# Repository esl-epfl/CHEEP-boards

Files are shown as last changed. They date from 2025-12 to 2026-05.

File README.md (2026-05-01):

# Welcome to the CHEEP boards!

This is a set of PCBs to test, in principle, [X-HEEP](github.com/esl-epfl/x-heep) chips (CHEEPs)... but, you can use it to test any chip you want, for what it matters.

The general idea is to recycle efforts, so all the things that are common to any CHEEP were moved into a **main board**. This one includes an FTDI through which you can program or communicate with your cheep, as well as some peripherals like flash, buttons, LEDs, etc. The main board also generates all the voltages needed by these blocks.

On the sides of the main board you will find slots for **chewing gums**, these are chewing-gum-shaped custom-boards that can do pretty much whatever you want them to. We have designed some that provide a configurable voltage and the extras needed to measure current being drained.

Almost everything that is on the main board, including the outputs of the chewing gums, go to a large 150-positions connector at the bottom of the PCB. You can then design for each cheep a custom **breakout board** that takes the signals that you need from that connector.

Bellow you can find some extra information on each of these parts.

## Main board

The objective of the mainboard is to include everything your cheep needs so that your breakout board can be as simple as a footprint for your cheep/socket wired to the connector.

It is controlled through a USB-C connector directly from your PC. From that USB you can power up the whole board and control the FTDI.

You can alternativelly power up the board with an external DC power supply through the jack of banana connector.

The FTDI is the same used on the [EPFL programmer](github.com/esl-epfl/x-heep-programmer-pmod), so you can directly command it through the `make` commands on X-HEEP.

The UART of the FTDI is also made available in the same way that it was on X-HEEP, so you just open picocom or any serial viewer to read the UART output of your CHEEP from your PC.

We use level shifters all around so that your chip can operate at any IO voltage you want. You can select the IO voltage on the main board through some jumpers with pre-defined values, or with a trimmer.

Additionally, through the FTDI you can control any of the I2C devices on the board, on the chewing gums, or on the breakout board. Check the [Software stack](./software_stack/) for the python tools for this. Components that are mapped include:
* **GPIO expanders** - so you can control (read/write) GPIOs and interface with your cheep through them (software stack pending)
* **PLL** - You can supply your cheep with different clocks, from 4 kHz to 200 MHz. Just check the [PLL software stack](./software_stack/python/pll_controller.py).
* **Chewing gums** - You can configure things on the chewing gums (e.g. read from on-board ADCs or set DAC values).

### 🪲 Bugs and needed improvements
* We need contributions on the software stack to control the chewing gums and on-board GPIOs.
* Setting different on-board IO voltages introduces weird behaviors on the LEDs, some of which are floating to be controlled by the breakout board. We should handle this better.

## 150 positions connector

You cancheck the [standard](./docs/150%20pin%20cheep%20board%20connector%20standard.pdf):


</p>

There is also a symbol and footprint you can use in your PCB to make sure you are using the right assignment.

## Chewing gums

So far we have designed 2 chewing gums that can be found on [the chewing gum folder](./chewing-gums/):

### PosNeg supply
As the name suggests, allows to produce a positive or negative supply (from the main-board-generated -5V reference).

### Current Measurement Supply

It's an voltage reference with a shunt to measure current. You can:
* Set the LDO reference through an on-board trimmer.
* Set the LDO reference through an on-board DAC (needs software stack to command it through I2C)
* Put different SMD resistor values (needs soldering :/)
* The shunt's voltage drop is amplified by an on-board amplifier (INA). Its output is made available on the SMA connector on the back. You can configure its gain through some pads on the bottom. You better measure against a known current before using these (e.g. I have measured the gain to be 1729 V/V with a 12 µV input referred offset with the default configurations). This will strongly affect your measurements!
* We left a 1 MΩ resistor to ground that you can use to make this calibration measurement.

## Creating your own

You can create your own chewing gum and contribute it to this project. You can use [the template](./chewing-gums/template/) to make sure you use the right footprint and pinout :)

### 🪲 Bugs and needed improvements
* We missed a 180 kΩ resistor in series between the DAC output and the LDO reference (in case you want to control them through DAC)
* It would be nice to have a TH connector for the shunt in case you want to use different ranges
* It would be nice to have a TH connector for the LDO resistive divider in case you want to use different ranges

## Your custom breakout board

You can make your own custom breakout board to take things from the main board and chewing gums. Whatever you are missing, you can always just add it to the breakout board, it ain't illegal...

You can take [the HEEPidermis breakout board](https://github.com/esl-epfl/HEEPidermis-breakout-board/tree/main) as an example.

## I2C Address Tree
The CHEEP mainboard uses TI TCA9548A (https://www.ti.com/lit/ds/symlink/tca9548a.pdf) I2C Multiplexers in order to allow to isolate the chewing gum boards from each other and to minimise the risk of I2C address conflicts.
### 0b1110000 / 0x70 - Left I2C Expander
#### PORT 0 - Chewing gum board 3
#### PORT 1 - Chewing gum board 2
#### PORT 2 - Chewing gum board 1
#### PORT 3 - Chewing gum board 4
#### PORT 4 - Chewing gum board 5
#### PORT 5 - Chewing Gum Board 6
#### PORT 6 - CHEEP CHIP PCB Connector
#### PORT 7 - CHEEP Board Infrastructure
#####
### 0b1110000 / 0x70 - Right I2C Expander

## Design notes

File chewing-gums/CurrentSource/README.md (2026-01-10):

# Overview

This chewing gum board is designed to be a current source and intended for connection to the main board through the male pin headers to both sides. It can produce a current output from 600 nA to 1.4 uA, usually as an external bias current to the analog blocks in the test chip.
# User guide and programmability

It is a single-channel current source based on the LM334 IC. It is capable of outputting from 600 nA to 1.4 uA using the resistor network, with a potentiometer that allows to adjust the output within this range. (Note that this output current range can be extended up to 10 mA by changing the values of resistors R2, R3 and RV1, check schematic and datasheet).

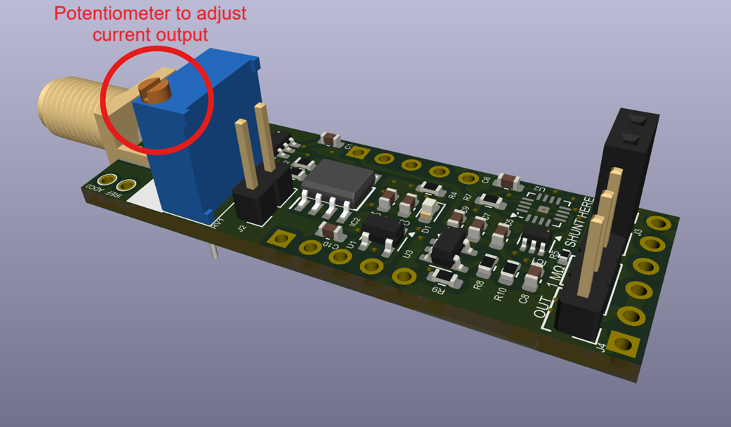
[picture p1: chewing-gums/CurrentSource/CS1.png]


The LM334 is powered by 3.3 V, however, unless the J2 jumper is connected, the current source IC will not be powered. Once it is powered-up by connecting the jumper, the LED should turn on.

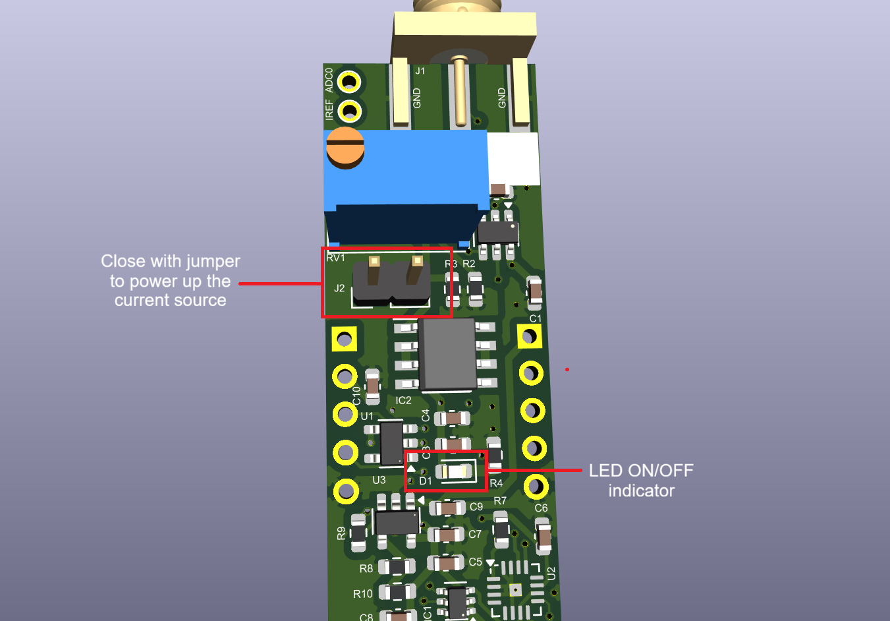
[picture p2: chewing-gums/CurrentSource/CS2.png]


Similar to other chewing gum boards (e.g., see _CurrentMeasurementSupply_), the current source board can be use to obtain a reading of the output current. All the current measurement circuits are kept unchanged and therefore can be used in the same way by employing shunt resistors + the ADC reading.

Female pin header J3 can be used to connect a through-hole resistor for current measurement. This allows for quicker replacement of the shunt resistor values, as opposed to the SMD alternatives.

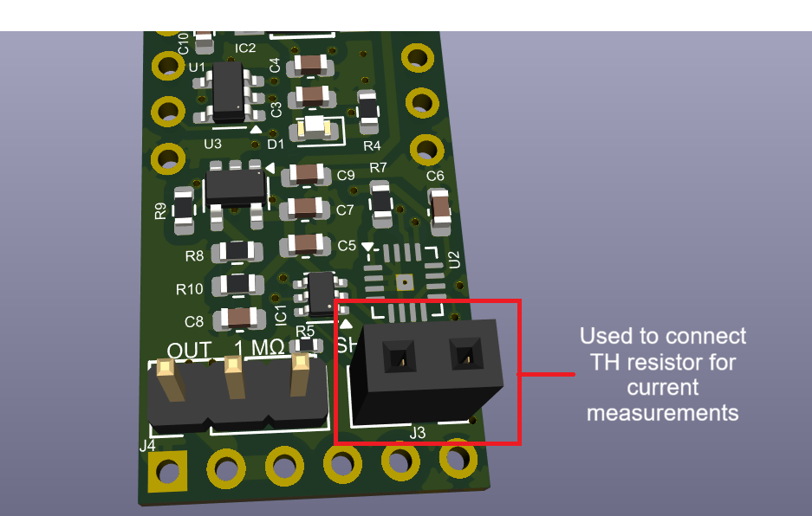
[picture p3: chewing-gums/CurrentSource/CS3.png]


The "IREF" test point next to the SMA connector can also be used to measure the voltage at the output of the current source. 

## Use of the DAC and EN pins

In this board, both the external EN pin to the board and the DAC are kept unused. This is because the current source IC is not compatible with either of these functions. However, the DAC is kept in the board for a possible future use.

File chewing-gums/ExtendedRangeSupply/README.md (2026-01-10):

# Overview

This chewing gum board is designed to be an extended-range voltage supply + current measurement circuit, intended for connection to the main board through the male pin headers to both sides. It can produce a voltage output from 0 to 5 V approximately, with currents of up to 1 A (@nominal voltage, check datasheet).
# User guide and programmability

This chewing gum board is an adaptation of the _CurrentMeasurementSupply_ chewing gum and as such can be used in a similar way, the main difference being the wider supply voltage range. This Extended Range version, however, supports only a single voltage output ("A").

It is based on the TPS7A9401 IC. The output voltage is defined via a resistor network, with a potentiometer soldered to the board that allows to manually modify the output within this range.

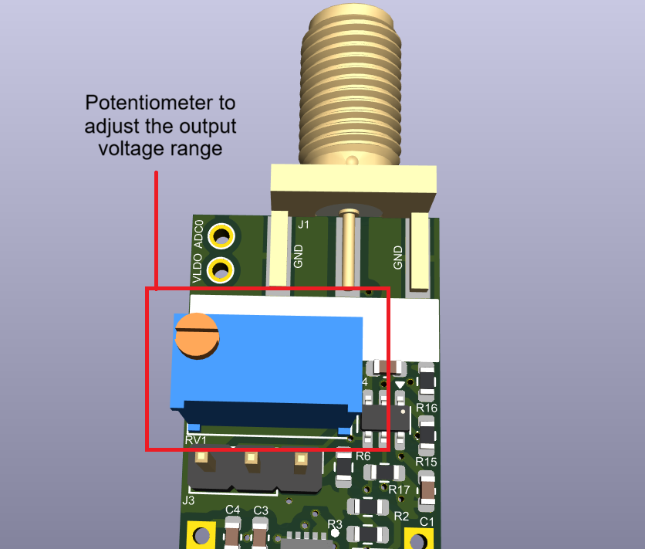
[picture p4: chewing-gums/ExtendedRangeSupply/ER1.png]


The TPS7A9401 is always ON and will operate when the EN pin is high. Either the external EN input, or the internal supply signal can be used to set the EN pin. This can be selected through the J2 jumper.

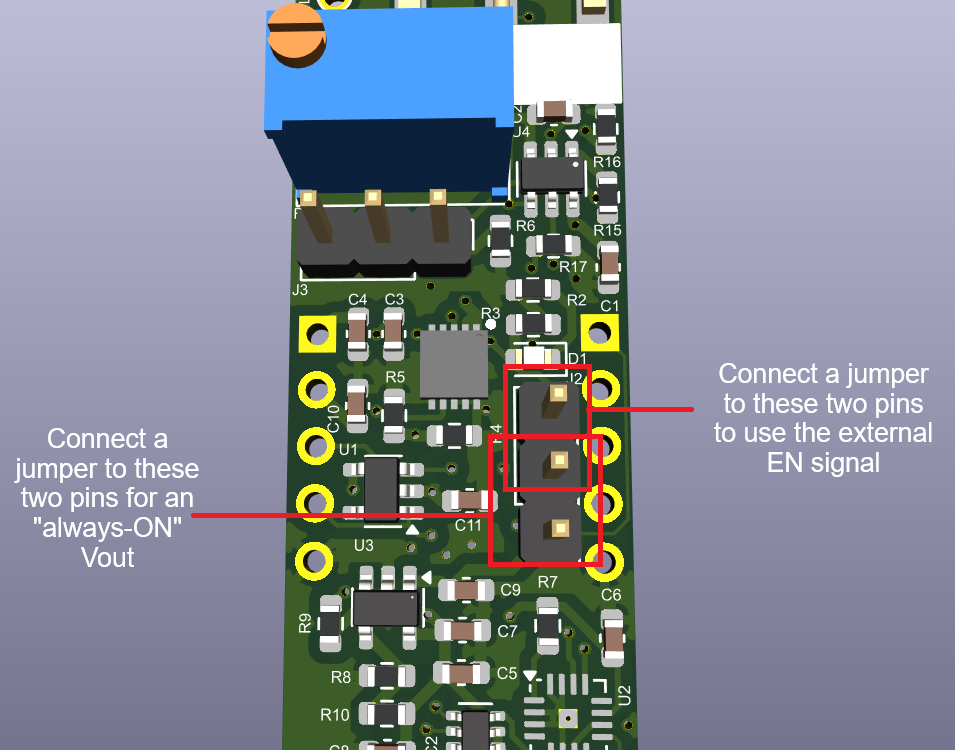
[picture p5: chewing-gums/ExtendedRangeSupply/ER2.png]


Similar to the _CurrentMeasurementSupply_ chewing gum board, this extended range version can also be use to obtain a reading of the output current. All the current measurement circuits are kept unchanged and therefore can be used in the same way by employing shunt resistors + the ADC reading. 

Female pin header J3 can be used to connect a through-hole resistor for current measurement. This allows for quicker replacement of the shunt resistor values, as opposed to the SMD alternatives.

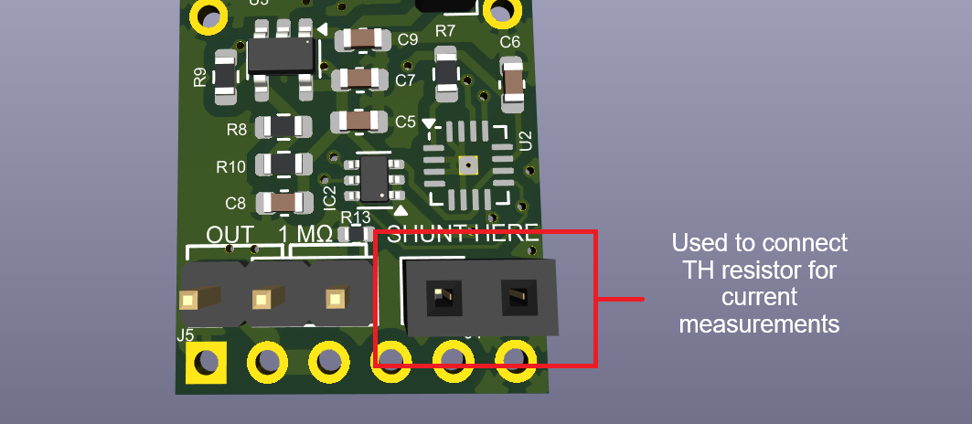
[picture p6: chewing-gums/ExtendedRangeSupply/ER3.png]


The "VLDO" test point next to the SMA connector can also be used to measure the output voltage.

## DAC programming

Besides using the potentiometer for trimming, the output voltage can also be adjusted by changing the input to the DAC. For this operation, however, resistors R15 and R16 need to be selected for this by carefully checking the possible voltage range with the datasheet.

Jumper J3 can be used to set potentiometer or DAC trimming.

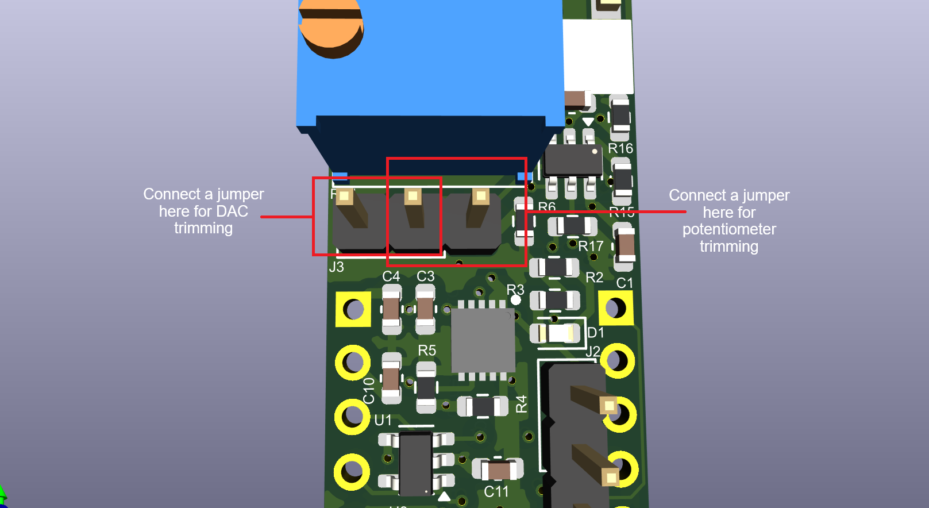
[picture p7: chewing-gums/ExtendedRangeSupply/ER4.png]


## Simulations

A macromodel of the TPS7A9401, together with a simplified circuit modeling its behavior in this board has been included. The simulation can be run using TINA-TI. This allows, for example, to change resistors and verify the output voltage of the TPS7A9401, as well as the output current when simulating with a load.

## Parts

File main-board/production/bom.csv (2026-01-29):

Designator | Footprint | Quantity | Value | LCSC Part #
C1, C10, C11, C12, C13, C14, C15, C16, C18, C2, C21, C24, C26, C27, C28, C29, C31, C32, C33, C34, C35, C36, C37, C38, C45, C46, C47, C49, C5, C50, C51, C52, C53, C54, C59, C65, C66, C7 | 0603 | 38 | 100nF | C30926
C17, C19, C60 | 0603 | 3 | 1uF | C15849
C20, C43 | 0603 | 2 | 10uF | C19702
C22, C30, C44 | 0603 | 3 | 22uF | C59461
C3, C4 | 0603 | 2 | 30pF | C1658
C39 | 0603 | 1 | 2.2uF | C1607
C40 | 0603 | 1 | 5.6nF | C1628
C41, C42, C8, C9 | 0603 | 4 | 4.7uF | C19666
C6 | 0603 | 1 | 3.3uF | C51412
C61 | CP_Elec_5x4.5 | 1 | 100uF | C7469933
D1, D10, D11, D12, D15, D16, D17, D18, D2, D3, D4, D5, D6, D7, D8, D9 | 0603 | 16 | LED | C84263
D13, D14 | D_SOD-882 | 2 | PESD3V3U1UL | C552530
D19, D20, D21, D22, D23, D24, D25 | 0603 | 7 | LED | C965804
D26 | 0603 | 1 | LED | C84266
IC10, IC2, IC3 | TI-UQFN-16 | 3 | SN74AXC4T774RSVR | C1849454
IC13 | TI-VQFN-HR-12 | 1 | TPS2121RUXR | C485916
J2, J66 | Banana_Jack_1Pin | 2 | Conn_01x01_Socket
J3 | PinSocket_1x04_P2.54mm_Vertical | 1 | Conn_01x04 | C124413
J47 | BarrelJack_GCT_DCJ200-10-A_Horizontal | 1 | Barrel Jack | C136744
J6 | PinHeader_1x03_P2.54mm_Vertical_SMD_Pin1Right | 1 | Conn_01x03 | C5160786
J7 | SMA_Amphenol_901-144_Vertical | 1 | Conn_Boaxial | C2987686
J73 | PinSocket_1x03_P2.54mm_Vertical | 1 | Conn_01x03 | C5116529
J8 | USB_C_Receptacle_GCT_USB4105-xx-A_16P_TopMnt_Horizontal | 1 | USB_C_Receptacle_USB2.0_16P | C5184243
J9 | PinHeader_2x04_P2.54mm_Vertical_SMD | 1 | Conn_02x04_Odd_Even | C192300
L1, L2 | 0603 | 2 | 600nH | C280244
L3 | L_Vishay_IHLP-2020 | 1 | 10uH | C844996
R1, R100, R101, R102, R103, R104, R105, R106, R107, R108, R109, R110, R12, R13, R24, R25, R26, R3, R31, R32, R33, R34, R35, R36, R37, R38, R39, R40, R41, R42, R45, R53, R65, R72, R80, R81, R82, R83, R84, R85, R86, R87, R88, R89, R90, R91, R92, R93, R94, R96, R97, R98, R99 | 0603 | 53 | 10k | C98220
R10, R11, R116, R117, R14, R16, R30, R74, R75 | 0603 | 9 | 1k | C21190
R111, R112, R113, R114, R115, R15, R17, R18, R19, R20, R21, R22, R23, R27, R63, R66, R77, R79, R95 | 0603 | 19 | 5k | C21190
R2 | 0603 | 1 | 12k 1% | C22790
R28, R29, R78 | 0603 | 3 | 5k | C22975
R4, R5, R70, R71 | 0603 | 4 | 25 | C1203
R43, R44, R58, R60 | 0603 | 4 | 5.1k | C23186
R46, R61 | 0603 | 2 | 100k | C25803
R47, R62, R69 | 0603 | 3 | 20k | C4184
R48 | 0603 | 1 | 51k | C23196
R49 | 0603 | 1 | 226k | C33619
R50 | 0603 | 1 | 49.9k | C23184
R51 | 0603 | 1 | 3.32M | C327396
R52 | 0603 | 1 | 1.33M | C482628
R54, R55 | 0603 | 2 | 5k | C22843
R56 | 0603 | 1 | 59k | C23085
R57, R59 | 0603 | 2 | 23.7k | C22912
R6, R7, R8, R9 | 0603 | 4 | 23.7k | C269480
R64 | 0603 | 1 | 4.7k | C99782
R67 | 0603 | 1 | 44.2k | C844365
R68 | 0603 | 1 | 86.6k | C23121
RV1 | Potentiometer_Bourns_3296W_Vertical | 1 | 500k | C83694
SW1, SW4, SW5, SW6, SW7 | SW_Push_1P1T_NO_CK_KMR2 | 5 | SW_Push | C221678
SW2 | SW_TE_1825255-1 | 1 | SW_DPST_x2
TP10, TP11, TP12, TP13, TP14, TP7, TP8, TP9 | TestPoint_Keystone_5019_Miniature | 8 | 5029 | C238131
U1 | LQFP-64_10x10mm_P0.5mm | 1 | FT4232HL | C56742
U10 | MSOP-10-1EP_3x3mm_P0.5mm_EP1.68x1.88mm | 1 | SI5351A-B-GTR | C504891
U11, U17 | TSSOP-20_4.4x6.5mm_P0.65mm | 2 | 74AHC244 | C7475
U12 | SOT-23-5 | 1 | 24AA02E-OT | C38987
U14, U28, U8 | VSSOP-10_3x3mm_P0.5mm | 3 | TS5A23159DGS | C42751
U15, U16 | BIWIN_DTS04GE_SMD | 2 | BIWIN_DTS04GE_SMD | C3294670
U18, U19 | SOT-23-5 | 2 | 74AHCT1G08 | C113521
U2 | SOIC-8_5.3x5.3mm_P1.27mm | 1 | W25Q128JVSIQ | C97521
U20 | SOT-23-5 | 1 | 74AHC1G04 | C7465
U21, U22 | Texas_RGE0024C_VQFN-24-1EP_4x4mm_P0.5mm_EP2.1x2.1mm | 2 | TCA9548ARGER | C555456
U23 | CHEEP_CONNECTOR_MAINBOARD | 1 | ~
U24 | Texas_R-PUQFN-N12 | 1 | TXBN0304RUT | C201558
U25, U26 | Texas_R-PUQFN-N12 | 2 | TXB0304RUT | C69598
U3, U5 | SOT-23-5 | 2 | TLV75801PDBV | C2877852
U4 | MAX17577-12-TDFN-EP | 1 | MAX17577 | C2930958
U6, U7 | WQFN-24-1EP_4x4mm_P0.5mm_EP2.6x2.6mm | 2 | TCAL6416 | C5956642
U9 | SOT-353_SC-70-5 | 1 | 74AHCT1G08 | C460499
X1 | Oscillator_SMD_SeikoEpson_SG8002CE-4Pin_3.2x2.5mm | 1 | OK322532.768KJBA4SL | C725996
Y1 | Crystal_SMD_3225-4Pin_3.2x2.5mm | 1 | Crystal_GND24 | C9002
Y2 | Crystal_SMD_3225-4Pin_3.2x2.5mm | 1 | NX3225GA-25.000M-STD-CRG-2 | C1985619

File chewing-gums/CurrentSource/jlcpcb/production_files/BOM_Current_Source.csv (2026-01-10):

Comment | Designator | Footprint | LCSC | Qty
0.1u | C1,C2,C4,C5,C6,C7,C8,C10 | Capacitor_SMD:C_0603_1608Metric | C1590 | 7
10k | R7,R9 | Resistor_SMD:R_0603_1608Metric | C98220 | 2
10u | C3 | Capacitor_SMD:C_0603_1608Metric | C19702 | 1
1u | C9 | Capacitor_SMD:C_0603_1608Metric | C1592 | 1
LED | D1 | LED_SMD:LED_0603_1608Metric | C2286 | 1
INA212AIDCKR | IC1 | Package_TO_SOT_SMD:SOT-363_SC-70-6 | C128622 | 1
LM334M_NOPB | IC2 | LM334:SOIC127P600X175-8N | C1524129 | 1
Conn_Coaxial | J1 | Connector_Coaxial:SMA_Amphenol_132289_EdgeMount | C1509219 | 1
75k | R2 | Resistor_SMD:R_0603_1608Metric | C2074221 | 1
140k | R3 | Resistor_SMD:R_0603_1608Metric | C860114 | 1
3.3k | R4 | Resistor_SMD:R_0603_1608Metric | C2907023 | 1
1M | R5 | Resistor_SMD:R_0402_1005Metric | C326730 | 1
20k | R8 | Resistor_SMD:R_0603_1608Metric | C4184 | 1
100k | R10 | Resistor_SMD:R_0603_1608Metric | C25803 | 1
500k Potentiometer | RV1 | Potentiometer_THT:Potentiometer_Bourns_3296W_Vertical | C83694 | 1
24AA02E-OT | U1 | Package_TO_SOT_SMD:SOT-23-5 | C38987 | 1
ADS1219 | U2 | Package_DFN_QFN:Texas_RTE0016D_WQFN-16-1EP_3x3mm_P0.5mm_EP0.8x0.8mm_ThermalVias | C2670319 | 1
TLV75801PDBV | U3 | Package_TO_SOT_SMD:SOT-23-5 | C2877852 | 1
MCP4726 | U4 | Package_TO_SOT_SMD:TSOT-23-6 | C191581 | 1

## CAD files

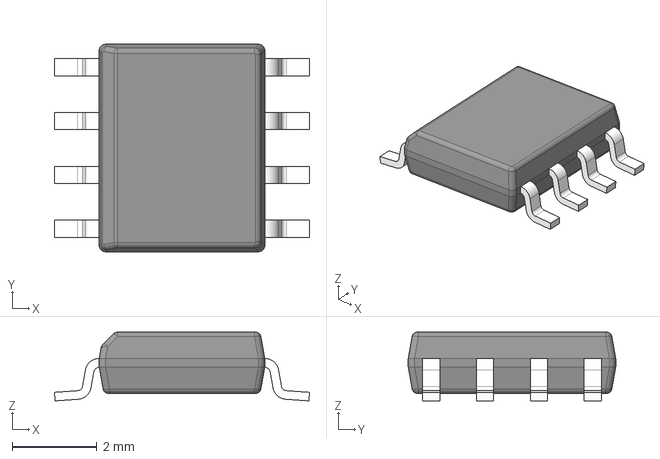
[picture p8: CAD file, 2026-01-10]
chewing-gums/CurrentSource/LM334/LM334M_NOPB.stp
6.02 x 4.90 x 1.63 mm
BODY-SO
LEAD-D0008A x 8

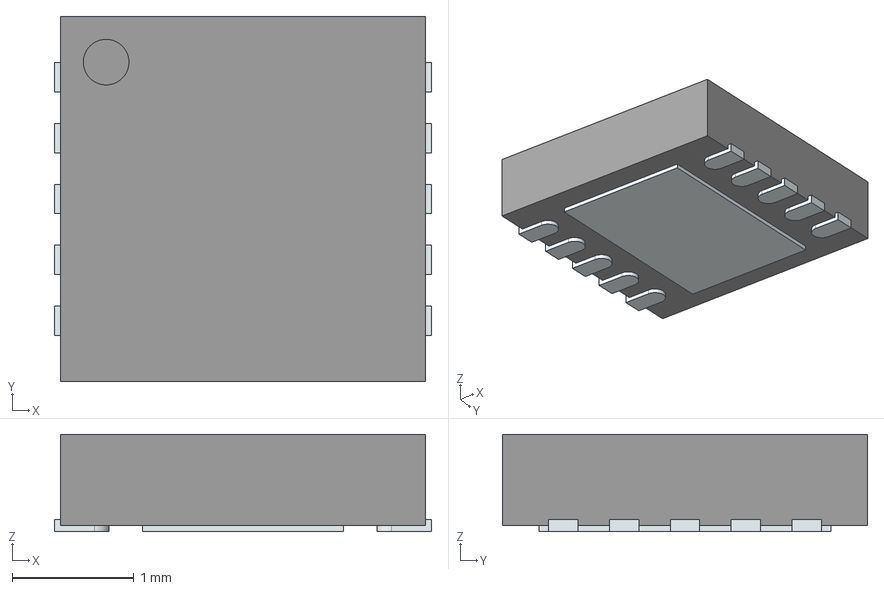
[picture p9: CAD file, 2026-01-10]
chewing-gums/ExtendedRangeSupply/TPS7A9401DSCR/TPS7A9401DSCR.stp
3.10 x 3.00 x 0.8 mm
ThermalPin
PinsArrayLR

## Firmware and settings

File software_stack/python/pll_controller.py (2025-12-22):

#from machine import Pin, I2C
from pll_i2c_wrapper import *
from pll_registers import PLLReg
#from utime import sleep_ms
from time import sleep



class PLLController:
    """
    Control PLL frequencies using an I2CWrapper.

    Attribuites:
        crystalFreq (int): Frequency of the srystal oscillator.

    Parameters:
        I2Cwrapper: Wrapper for I2C communication.
        crystalFreq (int): Frequnecy of the crystal oscillator. Defaults to PLLReg.CRYSTAL_FREQ_25MHZ.
    Reference:
        https://github.com/roseengineering/MicroPython-si5351.py
    """

    def __init__(self, I2CWrapper, crystalFreq = PLLReg.CRYSTAL_FREQ_25MHZ) -> None:
        """
        Initialize the PLLController.

        Parameters:
            I2CWrapper: Wrapper for I2C communication.
            crystalFreq (int): Frequency of the crystal oscialltor. Defaults to PLLReg.CRYSTAL_FREQ_25MHZ.


        """
        self.crystalFreq = crystalFreq
        self.plla_freq = 0
        self.communication = I2CWrapper

        clk_control_mapping = {
            0:  PLLReg.CLK0_CONTROL,
            1:  PLLReg.CLK1_CONTROL,
            2:  PLLReg.CLK2_CONTROL,
            3:  PLLReg.CLK3_CONTROL,
            4:  PLLReg.CLK4_CONTROL,
            5:  PLLReg.CLK5_CONTROL,
            6:  PLLReg.CLK6_CONTROL,
            7:  PLLReg.CLK7_CONTROL
        }
        self.clk_control_dict = clk_control_mapping

        multisynth_parameter1_mapping = {
            0: PLLReg.MULTISYNTH0_PARAMETERS_1,
            1: PLLReg.MULTISYNTH1_PARAMETERS_1,
            2: PLLReg.MULTISYNTH2_PARAMETERS_1,
            3: PLLReg.MULTISYNTH3_PARAMETERS_1,
            4: PLLReg.MULTISYNTH4_PARAMETERS_1,
            5: PLLReg.MULTISYNTH5_PARAMETERS_1,
            6: PLLReg.MULTISYNTH6_PARAMETERS_1
        }
        self.multisyn_p1 = multisynth_parameter1_mapping

        multisynth_parameter3_mapping = {
            0: PLLReg.MULTISYNTH0_PARAMETERS_3,
            1: PLLReg.MULTISYNTH1_PARAMETERS_3,
            2: PLLReg.MULTISYNTH2_PARAMETERS_3,
            3: PLLReg.MULTISYNTH3_PARAMETERS_3,
            4: PLLReg.MULTISYNTH4_PARAMETERS_3,
            5: PLLReg.MULTISYNTH5_PARAMETERS_3,
            6: PLLReg.MULTISYNTH6_PARAMETERS_3
        }
        self.multisyn_p3 = multisynth_parameter3_mapping


        #reset all clk outputs
        self.reg_write(PLLReg.OUTPUT_ENABLE_CONTROL, 0xFF)
        for clk_ctrl in range(0,8):
            self.reg_write(self.clk_control_dict.get(clk_ctrl), 0x80)

    def reg_write(self, address, data) -> None:
        """
        Write data to register.

        Parameter:
            address (int): Register address.
            data (int): Data to be written to the register.
        """

        self.communication.write_data(address, data)

    def reg_read(self, address: int) -> int:
        """
        Read data from a register.

        Parameters:
            address (int): Register address.

        Returns:
            int: Data read from the register.
        """
        data = self.communication.read_data(address, num_bytes=1)
        return data


    def set_frequency(self, target_frequency: int, output: int = 0, pll: int = PLLReg.PLL_A, mult: int = 32, roundit: bool = False) -> None:
        """
        Set the frequency of the PLL to the target_frequency.
        Decides if a frequency is below the minimum frequency. R divider needed for frequency lower then 500kHz down to 4kHz.
        Checks if the desired frequency is less then 500kHz down to 4kHz. If so then use resistors.
        Initilaize the Feedback Multiplier.

        Parameters:
            target_frequency (int): Desired frequency for the PLL.
            output (int): Choose the output clock (clk0-clk7).
            pll (int): Choose which PLL (A or B) provides f_vco.
            roundit (bool): Rounds fraction division to nearest int value. Reduces jitter by loss of frequency precision.
        """
        print(f"------------------------------------\n Set frequency to \n {target_frequency} \n")

        if (target_frequency >= 120_000_000):
            self.high_speed(target_frequency, output, pll, roundit)
            return

        mult = 36 # input clk multiplier must be between 15 and 90

        self.setup_feedbackMultisynth(pll, mult, 0, 1)

        freq = target_frequency
        r_div = PLLReg.R_DIV_1
        register = 60 #MULTISYNTH2_PARAMETERS_1
        print("R not hitted")
        if (freq >= PLLReg.CLKOUT_MIN_FREQ and freq < PLLReg.CLKOUT_MIN_FREQ * 2):
            r_div = PLLReg.R_DIV_128
            freq *= 128
            print(f"R hitted: {r_div}")
        elif (freq >= PLLReg.CLKOUT_MIN_FREQ*2 and freq < PLLReg.CLKOUT_MIN_FREQ * 4):
            r_div = PLLReg.R_DIV_64
            freq *= 64
            print(f"R hitted: {r_div}")
        elif (freq >= PLLReg.CLKOUT_MIN_FREQ*4 and freq < PLLReg.CLKOUT_MIN_FREQ * 8):
            r_div = PLLReg.R_DIV_32
            freq *= 32
            print(f"R hitted: {r_div}")
        elif (freq >= PLLReg.CLKOUT_MIN_FREQ*8 and freq < PLLReg.CLKOUT_MIN_FREQ * 16):
            r_div = PLLReg.R_DIV_16
            freq *= 16
            register = 44 # MULTISYNTH0_PARAMETERS_1
            print(f"R hitted: {r_div}")
        elif (freq >= PLLReg.CLKOUT_MIN_FREQ*16 and freq < PLLReg.CLKOUT_MIN_FREQ * 128):
            r_div = PLLReg.R_DIV_8
            freq *= 8
            register = 44 # MULTISYNTH0_PARAMETERS_1
            print(f"R hitted: {r_div}")
        elif (freq >= PLLReg.CLKOUT_MIN_FREQ*32 and freq < PLLReg.CLKOUT_MIN_FREQ * 64):
            r_div = PLLReg.R_DIV_4
            freq *= 4
            print(f"R hitted: {r_div}")
        elif (freq >= PLLReg.CLKOUT_MIN_FREQ*64 and freq < PLLReg.CLKOUT_MIN_FREQ * 128):
            r_div = PLLReg.R_DIV_2
            freq *= 2
            print(f"R hitted: {r_div}")

        if pll == PLLReg.PLL_A:
            fvco = self.plla_freq
        else:
            fvco = self.pllb_freq

        print(f"fvco: {fvco}")
        print(f"freq: {freq}")

        if roundit == True:
            num = fvco % freq
            denom = freq
            value = num/denom
            num = 0
            denom = 1
            div = fvco//freq
            if value >= 0.5:
                div += 1
        else:
            div = fvco // freq
            num = fvco % freq
            denom = freq

            if num == 0:
                denom = 1
            else:
                while denom > PLLReg.MULTISYNTH_C_MAX:
                    num //= 2
                    denom //= 2



        self.reset_pll()

        oe_ctrl = self.reg_read(PLLReg.OUTPUT_ENABLE_CONTROL)
        oe_cfg = oe_ctrl&(~(1<<output))
        print("oeb: {0:b}".format(oe_cfg))
        self.reg_write(PLLReg.OUTPUT_ENABLE_CONTROL, oe_cfg) #enable output clock

        self.setupMultisynth(output, div, num, denom)

        self.setupRdiv(output, r_div, register)



    def high_impedance(self, enable: bool) -> None:
        """
        Set the output of the PLL as high impedance if enable = True

        Parameters:
            enable (bool): Enable or disable high impedance.

        """
        self.reg_write(address=PLLReg.OUTPUT_ENABLE_CONTROL, data = 4 * enable) #maybe find a way to not have this 4 magic number


    def setup_feedbackMultisynth(self, pll: int, mult: int, num: int = 0, denom: int = 1) -> None:
        """
        Setup the feedback Multipath.

        Parameter:
            pll (int): Choose which PLL (A or B) provides f_vco.
            mult (int): PLL integer multiplier (must be between 15 and 90).
            num (int, optional): The 20-bit numerator for fractional output (0..1,048,575). Defaults to 0.
            denom (int, optional): The 20-bit numerator for fractional output (0..1,048,575). Defaults to 1.
        """
        print(f"\n Set feedback Multisynth \n")

        # Set the main PLL config registers
        print(f"mult: {mult}, num: {num}, denom: {denom}")

        P1 = 128 * mult + int(128.0 * num / denom) - 512
        P2 = 128 * num - denom * int(128.0 * num / denom)
        P3 = denom

        print(f"P1: {P1}")
        print(f"P2:  {P2}")
        print(f"P3:  {P3}")

        baseaddr = 26 if pll == PLLReg.PLL_A else 34 #Register 34 for use of PLLB

        self.reg_write(baseaddr,     (P3 & 0x0000FF00) >> 8)
        #isolate bits[15:8] and send it to the register
        self.reg_write(baseaddr + 1, (P3 & 0x000000FF))
        self.reg_write(baseaddr + 2, (P1 & 0x00030000) >> 16)
        self.reg_write(baseaddr + 3, (P1 & 0x0000FF00) >> 8)
        self.reg_write(baseaddr + 4, (P1 & 0x000000FF))
        self.reg_write(baseaddr + 5, ((P3 & 0x000F0000) >> 12) | ((P2 & 0x000F0000) >> 16) )
        #P3 should also be shifted by 12 ??
        self.reg_write(baseaddr + 6, (P2 & 0x0000FF00) >> 8)
        self.reg_write(baseaddr + 7, (P2 & 0x000000FF))

        fvco = int(self.crystalFreq*mult + float(num) /denom)
        if pll == PLLReg.PLL_A:
            self.plla_freq = fvco
        else:
            self.pllb_freq = fvco


    def setupMultisynth(self, output: int, div: int, num: int, denom: int) -> None:
        """
        Setup Multisynth divider, which  determines the output clock frequency based on the specified PLL input.

        Parameter:
            output (int): Output channel to choose.
            pll (int): PLL input source (now only PLLA since we don't use spread or VCXO).
            div (int): Integer divider for Multisynth output.
            num (int): The 20-bit numerator for fractional output (0..1,048,575). Set this to '0' for integer output.
            denom (int): The 20-bit numerator for fractional output (0..1,048,575). Set this to '0' for integer output.
        """
        print(f"\n Set setup Multisynth \n")

        print(f"divisor {div}")

        # Set the main PLL config registers
        P1 = 128 * div + int(128.0 * num / denom) - 512
        P2 = 128 * num - denom * int(128.0 * num / denom)
        P3 = denom

        print(f"P1: {P1}")
        print(f"P2:  {P2}")
        print(f"P3:  {P3}")
        print(f"divisor: {div}, num: {num}, denom: {denom}")

        baseaddr = self.multisyn_p3.get(output)

        print(f"baseaddr: {baseaddr}")

        self.reg_write(baseaddr,     (P3 & 0x0000FF00) >> 8)

        #isolate bits[15:8] and send it to the register
        self.reg_write(baseaddr + 1, (P3 & 0x000000FF))
        self.reg_write(baseaddr + 2, (P1 & 0x00030000) >> 16)
        self.reg_write(baseaddr + 3, (P1 & 0x0000FF00) >> 8)
        self.reg_write(baseaddr + 4, (P1 & 0x000000FF))
        self.reg_write(baseaddr + 5, ((P3 & 0x000F0000) >> 12) | ((P2 & 0x000F0000) >> 16) )

        #P3 should also be shifted by 12 ??
        self.reg_write(baseaddr + 6, (P2 & 0x0000FF00) >> 8)
        self.reg_write(baseaddr + 7, (P2 & 0x000000FF))

        #configure the clk control and enable output
        #8mA drive strength, MS0 as CLK0 source, Clock not inverted, power up

        clkControlReg = 0x0F
        if num == 0 : clkControlReg |= (1 << 6) #sets register in integer mode

        self.reg_write(self.clk_control_dict.get(output), clkControlReg) # here if condition for multiple clock output

    def high_speed(self, target_frequency: int, output: int, pll: int, roundit: bool) -> None:
        """
        Sets frequencies from 120Mhz to 200Mhz (overclock possible up to 300MHz)

         Parameters:
            target_frequency (int): Desired frequency for the PLL.
            output (int): Choose the output clock (clk0-clk7).
            pll (int): Choose which PLL (A or B) provides f_vco.
            roundit (bool): Rounds fraction division to nearest int value. Reduces jitter by loss of frequency precision.
        """

        self.setupMultisynth(output, 4, 0, 1) # set the output_Multisynth to the needed divisor 4

        self.setupRdiv(output, PLLReg.R_DIV_1)

        #set the Multisynth2 Parameter to Divide by 4 Enable
        divby4 = self.reg_read(self.multisyn_p1.get(output))
        print(f"data type from read is: {divby4}")
        divby4 |= 0xC #set the register value to Divide by 4
        self.reg_write(self.multisyn_p1.get(output), divby4)

        clkControlReg = self.reg_read(self.clk_control_dict.get(output))
        clkControlReg |= (1<<6) #set the control_setup to integer mode
        self.reg_write(self.clk_control_dict.get(output), clkControlReg)

        div = (target_frequency*4) // PLLReg.CRYSTAL_FREQ_25MHZ
        num = ((target_frequency*4) % PLLReg.CRYSTAL_FREQ_25MHZ)//1_000_000
        denom = PLLReg.CRYSTAL_FREQ_25MHZ//1_000_000

        if roundit == True:
            value = num/denom
            num = 0
            denom = 1
            if value >= 0.5:
                div += 1

        self.reg_write(PLLReg.CRYSTAL_INTERNAL_LOAD_CAPACITANCE, PLLReg.CRYSTAL_LOAD_8PF)

        self.setup_feedbackMultisynth(pll, div, num, denom)

        self.reset_pll()

        oe_ctrl = self.reg_read(PLLReg.OUTPUT_ENABLE_CONTROL)
        oe_cfg = oe_ctrl&(~(1<<output))
        print("oeb: {0:b}".format(oe_cfg))
        self.reg_write(PLLReg.OUTPUT_ENABLE_CONTROL, oe_cfg) #enable output clock

        print("high speed frequency")
        return


    def setupRdiv(self, output: int = 2, div: int = 1, register=60) -> None:
        """
        Setup the R divisor, for only one outpupt clk

        Parameter:
            output (int): Output channel to choose.
            div (int): Interger divider.
        """
        print(f"output = {output}")
        Rreg = self.multisyn_p1.get(output)
        print(f"output number = {Rreg}")
        print(f"in register: {bin((div & 0x07) << 4)}")
        return self.reg_write(register, (div & 0x07) << 4)

    def enableOutput(self, enabled: bool) -> None:
        """
        Enables the selected output

        Parameter:
            enabled (bool): Whether the output should be enabled.
        """
        val = 0x00 if enabled else 0xFF
        self.reg_write(PLLReg.OUTPUT_ENABLE_CONTROL, val)

    def pll_stuck(self) -> int:
    # pylint: disable= line-too-long
        """
        Check Crystal Loss of Signal.

        Parameters:
            None

        Returns:
            int: 0 if valid crystal signal at the XA and XB Pins, 1 if loss of crystal signal detected.
        """
        print("checked stuck")
        status = (self.reg_read(0)>>3) & 0b1
        print(f"pllstuck_status: {status}")
        return status

    def reset_pll(self) -> None:
        """
        Resets the PLL.

        Parameters:
            None
        """

        #reset the PLL
        self.reg_write(PLLReg.PLL_RESET_REGISTER_177, (1<<7) | (1<<5))

    def powerdown(self, output: int) -> None:
        """
        Power down the output of the given clock.

        Parameters:
            output (int): Choose the output clock (clk0-clk7).
        """
        clkControlReg = self.reg_read(self.clk_control_dict.get(output))
        clkControlReg |= (1<<7) #write a one at specific bit
        self.reg_write(self.clk_control_dict.get(output), clkControlReg)

    def powerup(self, output: int) -> None:
        """
        Power up the output of the given clock.

        Parameters:
            output (int): Choose the output clock (clk0-clk7).
        """
        clkControlReg = self.reg_read(self.clk_control_dict.get(output))
        clkControlReg = clkControlReg & ~(1<<7) #write a zero at specific bit
        self.reg_write(self.clk_control_dict.get(output), clkControlReg)

    def invertclk(self, output: int) -> None:
        """
        Invert the output clock.

        Parameters:
            output (int): Choose the output clock (clk0-clk7).
        """
        clkControlReg = self.reg_read(self.clk_control_dict.get(output))
        clkControlReg = clkControlReg ^ (1<<4) #flip bit by xor it
        self.reg_write(self.clk_control_dict.get(output), clkControlReg)

    def drive_strength(self, output: int, strength: int)-> None:
        """
        Set the drive strength for the given output.

        Parameters:
            output (int): Choose the output clock (clk0-clk7).
            strength (int): Choose the driving strength (2, 4, 6, 8mA).
        """
        clkControlReg = self.reg_read(self.clk_control_dict.get(output))
        if strength == 2:
            clkControlReg = clkControlReg & ~(1<<0)
            clkControlReg = clkControlReg & ~(1<<1)
        if strength == 4:
            clkControlReg = clkControlReg & ~(1<<1)
            clkControlReg |= (1<<0)
        if strength == 6:
            clkControlReg = clkControlReg & ~(1<<0)
            clkControlReg |= (1<<1)
        if strength == 8:
            clkControlReg |= (1<<0)
            clkControlReg |= (1<<1)
        self.reg_write(self.clk_control_dict.get(output), clkControlReg)

    def multisyn_source(self, output: int, pll: int):
        """
        Choose the MultiSynth Source.

        Parameters:
            output (int): Choose the output clock (clk0-clk7).
            pll (int): Choose which PLL (A or B) provides f_vco.
        """
        clkControlReg = self.reg_read(self.clk_control_dict.get(output))
        if pll == 0:
            clkControlReg = clkControlReg & ~(1<<5)
        if pll == 1:
            clkControlReg |= (1<<5)
        self.reg_write(self.clk_control_dict.get(output), clkControlReg)

    def sweep_freq(self, start_freq: int, end_freq: int, step_size: int, period: int, output: int, pll: int, roundit: bool):
        """
        Function that sweeps a given frequency range with the given timestep.

        Parameters:
            start_freq (int): Starting point for the sweep.
            end_freq (int): End point of the sweep.
            step_size (int): Size between each step.
            period (int): Time between each step.
            output (int): Choose the output clock (clk0-clk7).
            pll (int): Choose which PLL (A or B) provides f_vco.
            roundit (bool): Rounds fraction division to nearest int value. Reduces jitter by loss of frequency precision.
        """
        for i in range(start_freq, end_freq+step_size, step_size):
            self.set_frequency(i, output, pll, 32 , roundit)
            sleep(period/1000)

    def hopping_freq(self, freq_array: list, amount: int, period: int, output: int, pll: int, roundit: bool) -> None:
        """
        Function that can be used to hop between frequency that are provided in freq_array

        Parameters:
        - freq_array (int): Array containing the frequencies to hop through.
        - amount (int): How often to itterate through the freq_array.
        - period (int): Time between each hop.
        - output (int):  Choose the output clock (clk0-clk7).
        - pll (int): Choose which PLL (A or B) provides f_vco.
        - roundit (bool): Rounds fraction division to nearest int value. Reduces jitter by loss of frequency precision.
        """
        length = len(freq_array)
        index = 0
        a = 0
        while a < amount:
            i = freq_array[index]
            self.set_frequency(i, output, pll, 32, roundit = roundit)
            sleep(period/1000)
            index = (index+1)%length
            a += 1

class FrequencyIterate:
    """
    Iterator for iterating over frequencies using PLLController.

    Attributes:
        current (int): Current frequency.

    Parameters:
        start_freq (int): Starting frequency.
        end_freq (int): Ending frequency.
        step_size (int): Size of each step.
        output (int): Output channel.
        pll (int): PLL input source.
        roundit (bool): Optional, rounds fractional division. Defaults to False.
    """
    def __init__(self, start_freq: int, end_freq: int, step_size: int, output: int, pll: int, roundit: bool = False) -> None:
        """
        Initialize the FrequencyIterate object.

        Parameters:
            start_freq (int): Starting frequency.
            end_freq (int): Ending frequency.
            step_size (int): Size of each step.
            output (int): Output channel.
            pll (int): PLL input source.
            roundit (bool): Optional
        """
        self.pll_controller = PLLController(I2CWrapper)
        self.current = start_freq
        self.end_freq = end_freq
        self.step_size = step_size
        self.output = output
        self.pll = pll
        self.pll_controller.set_frequency(self.current, self.output, self.pll, roundit = roundit)

    def __iter__(self) -> None:
        """
        Returns the iteratir object itself.
        """
        return self

    def __next__(self) -> None:
        """
        Returns the next item in the sequence.
        """
        self.current += step_size
        self.pll_controller.set_frequency(self.current, self.output, self.pll, roundit = roundit)
        if self.current < self.end_freq:
            return self.current
        raise StopIteration


if __name__ == "__main__":
    # Example usage of the I2CWrapper and PLLController classes
    roundit = False

    # Set the PLL frequency
    target_frequency = 300_000  # Example frequency in Hz
    #pll_controller.set_frequency(target_frequency, 2, PLLReg.PLL_A, roundit)
    #pll_controller.set_frequency(target_frequency*4, 2, PLLReg.PLL_B, roundit)

    freq_array = [31_000, 33_000]

    start_freq = 120_000_000
    end_freq = 150_000_000
    step_size = 5_000_000
    period = 2000
    output = 2
    pll = PLLReg.PLL_A
    amount = 100

    # iterator = FrequencyIterate(start_freq, end_freq, step_size, output, pll)
    # myiter = iter(iterator)
    # next(myiter)
    # sleep(2000)
    # print("next")
    # next(myiter)
    # sleep(2000)
    # print("next")
    # next(myiter)

    #pll_controller.invertclk(output)
    #pll_controller.powerdown(output)
    #pll_controller.powerup(output)

    #pll_controller.hopping_freq(freq_array, amount, period, output, pll, roundit)

    #pll_controller.sweep_freq(start_freq, end_freq, step_size, period, output, pll, roundit)

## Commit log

2025-08-29 Renamed the project
    [HEEPocrates.kicad_sch, LevelTransMeasCurrent.kicad_sch, PowerHTB.kicad_sch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]
2025-08-29 Initial split into sub-projects
    [HEEPocrates.kicad_sch, LevelTransMeasCurrent.kicad_sch, PowerHTB.kicad_sch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]
2025-09-02 First version of the chewing gum Vdc
    [chewing-gum.kicad_pcb, chewing-gum.kicad_sch, heepidermis-bo.kicad_pcb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]
2025-09-04 Finished ADC/DAC board
    [adc-dac.kicad_pcb, chewing-gum.kicad_pcb, chewing-gum.kicad_sch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]
2025-09-05 re-arranged adc/dac and routed to the cgs
    [LevelTransMeasCurrent.kicad_sch, Programmer.kicad_sch, adc-dac.kicad_pcb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]
2025-09-08 Before re-organizing the main board
    [LevelTransMeasCurrent.kicad_sch, Programmer.kicad_sch, chewing-gum.kicad_pcb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]
2025-09-08 tested main board side by side
    [main-board.kicad_pcb]
2025-09-10 Before re-routing programmer
    [LevelTransMeasCurrent.kicad_sch, Programmer.kicad_sch, cheep-connector.kicad_sch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]
2025-09-15 WIP: added i2c expanders and re-structuring i2c distributino
    [LED_driver.kicad_sch, LevelTransMeasCurrent.kicad_sch, Programmer.kicad_sch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]
2025-09-15 Routed all power signals and re-organized GPIOs
    [cheep-connector.kicad_sch, chewing-gums.kicad_sch, gpio_playground.kicad_sch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]
2025-09-30 rework main PCB: added USB-C, new connector symbol & footprints
    [LevelTransMeasCurrent.kicad_sch, Programmer.kicad_sch, cheep-connector.kicad_sch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]
2025-10-01 Connector bugfixing, added new connector to layout
    [cheep-connector.kicad_sch, main-board.kicad_sch]
2025-10-02 update testing board
    [LevelTransMeasCurrent.kicad_sch, cheep-connector.kicad_sch, chewing-gums.kicad_sch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]
2025-10-03 pcb update
    [cheep-connector.kicad_sch, gpio_playground.kicad_sch, main-board.kicad_sch]
2025-10-06 adding nA gum schematic, symbols and jupyter notebook calculations
    [nA_current_shunt_monitor_gum.kicad_pcb, nA_current_shunt_monitor_gum.kicad_sch]
2025-10-07 adding PCB layout for nA gum
    [nA_current_shunt_monitor_gum.kicad_pcb, nA_current_shunt_monitor_gum.kicad_sch]
2025-10-07 adding EEPROM in sch + fix symbol connector gum
    [nA_current_shunt_monitor_gum.kicad_pcb, nA_current_shunt_monitor_gum.kicad_sch]
2025-10-07 Finish gum pcb layout with EEPROM
    [nA_current_shunt_monitor_gum.kicad_pcb]
2025-10-10 Testing board final version & production data
    [BOM-main-board.csv, LevelTransMeasCurrent.kicad_sch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]
2025-10-13 Dual bias gum
    [1p6V_to_m1p6V_bias_gum.kicad_pcb, 1p6V_to_m1p6V_bias_gum.kicad_sch]
2025-10-31 production files
    [1p6V_to_m1p6V_bias_gum-CuBottom.gbr, 1p6V_to_m1p6V_bias_gum-CuIn1.gbr, 1p6V_to_m1p6V_bias_gum-CuIn2.gbr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]
2025-11-20 software stack added, renamed chewing gums to match the software stack
    [1p6V_to_m1p6V_bias_gum-CuBottom.gbr, 1p6V_to_m1p6V_bias_gum-CuIn1.gbr, 1p6V_to_m1p6V_bias_gum-CuIn2.gbr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]
2025-11-21 openocd config file
    [cheep-main-xheep.cfg]
2025-11-21 cleanup: old version of the heepidermis board. (seperate repository))
    [heepidermis-bo.kicad_pcb, heepidermis-bo.kicad_sch]
2025-12-22 cleaned repo and added documentation
    [HEEPocrates.kicad_sch, LevelTransMeasCurrent.kicad_sch, PowerHTB.kicad_sch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]
2025-12-22 corrected pin diagram visualization
2026-01-10 ✨ New chewing gums: Extended-range voltage supply and current source (#1)
    * Adding 2 new chewing gums: Extended range supply & Current source
    ---------
    [BOM_Current_Source.csv, BOM_Extended_Range_Supply.xlsx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]
2026-01-28 🪲🔫 Fixed bugs on polarities
    [main-board.kicad_sch]
2026-01-29 Cleaned production files
    [BOM-main-board.csv, bom.csv, heepocrates.csv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]
2026-01-30 Reflected changes on sch
    [LevelTransMeasCurrent.kicad_sch, main-board.kicad_sch, positions.csv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]
